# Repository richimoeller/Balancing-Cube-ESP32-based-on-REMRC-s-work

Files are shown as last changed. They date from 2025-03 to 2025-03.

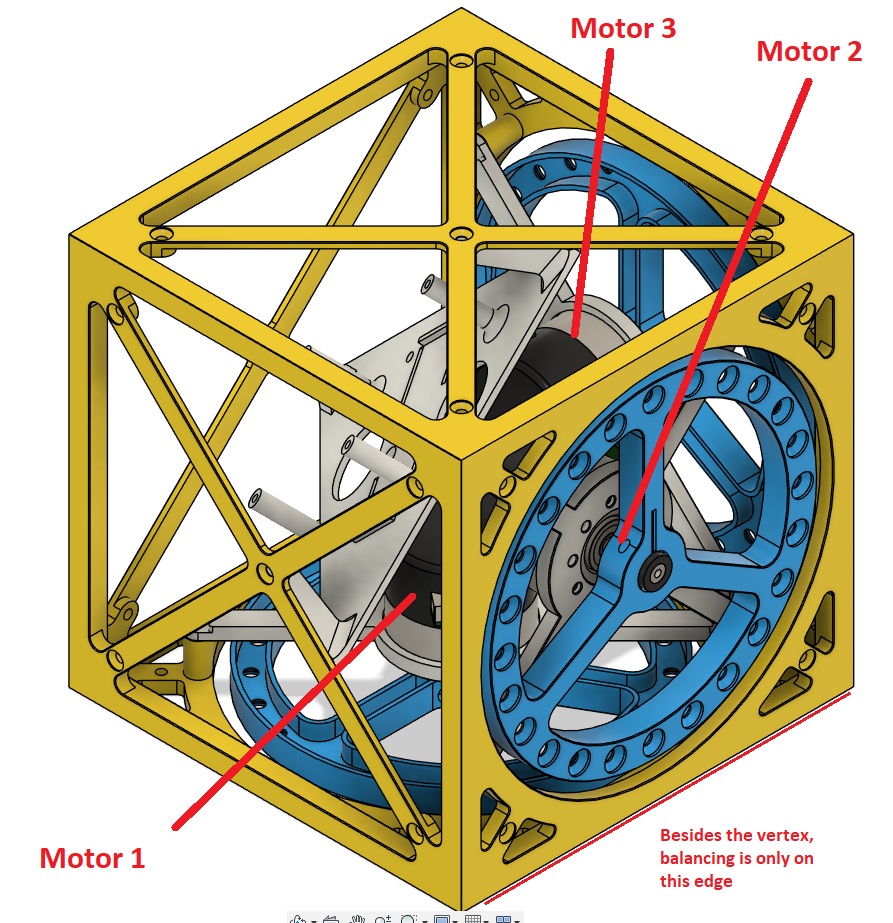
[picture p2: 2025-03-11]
pictures/orientation_motors.jpg

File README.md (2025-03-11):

Balancing Cube ESP32 based on REMRC's work
------------------------------------------

There already a few cubes out there based on REMRCs design.

All the credits go to him.

I redesigned the cube in Fusion 360 since I wanted to have an unobstructed view at the reaction wheels. All other parts are following closely REMRC's design.
Basically the cube worked right from the start with no changing of the tuning parameters needed. My reaction wheels have a weight of 72g. I use a 11,1V 550mAh battery.
The code uses the encoders. You have to wire them to the ESP32(30pin). I needed to change the code a little because the pwm_channel assignment used by REMRC is deprecated meanwhile.

Just follow the calibration procedure provided by REMRC.

I also added the functionality of letting the cube turn on its vertex by sending the commands r+, r- and rs(Stop) via a bluetooth terminal. However the cube will not turn forever in one direction. The wheels will speed up and eventually saturate. Just change the direction or stop it in due time. 

https://www.youtube.com/watch?v=GABWHTa6_v8

I added motor numbers to the schematic as well as to the 3D picture. This way you should be able to connect the motors in the correct order right from the beginning. Feel free to use the Fritzing-board provided. 

It's an amazing project. Enjoy!!

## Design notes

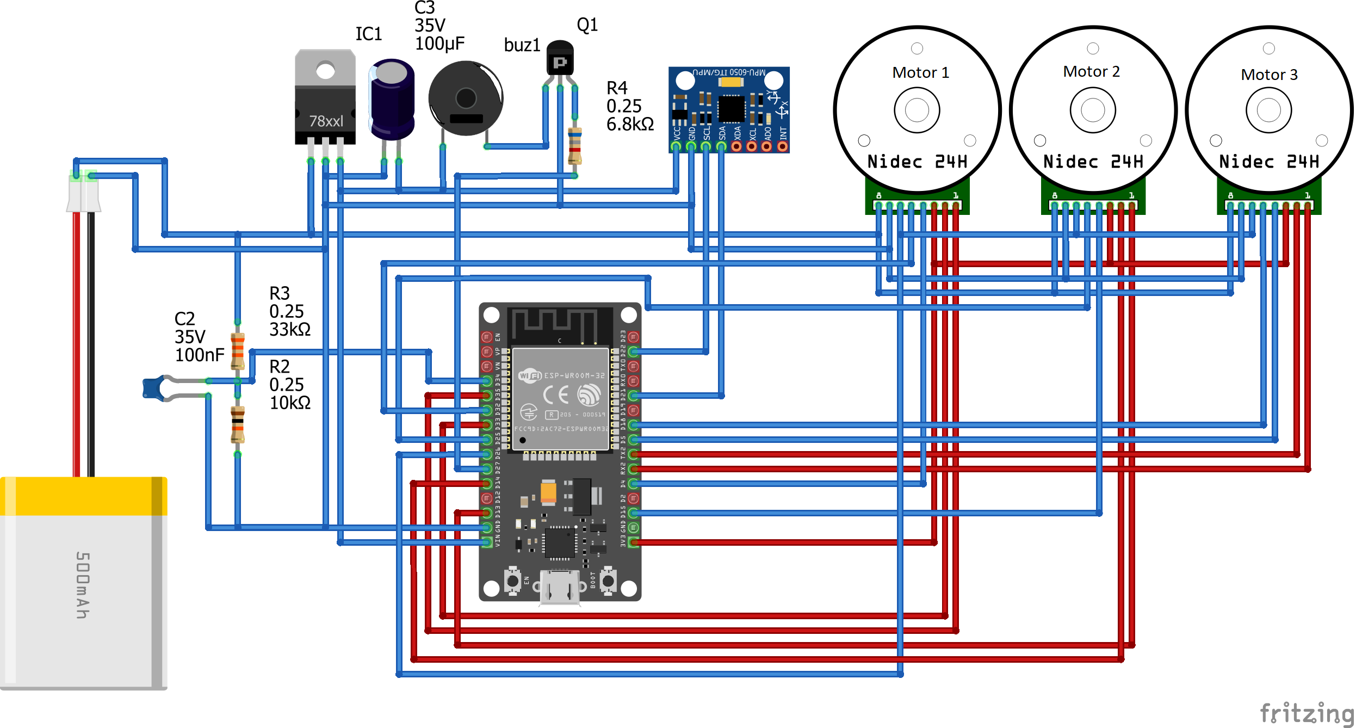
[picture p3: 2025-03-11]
pictures/schematic.png

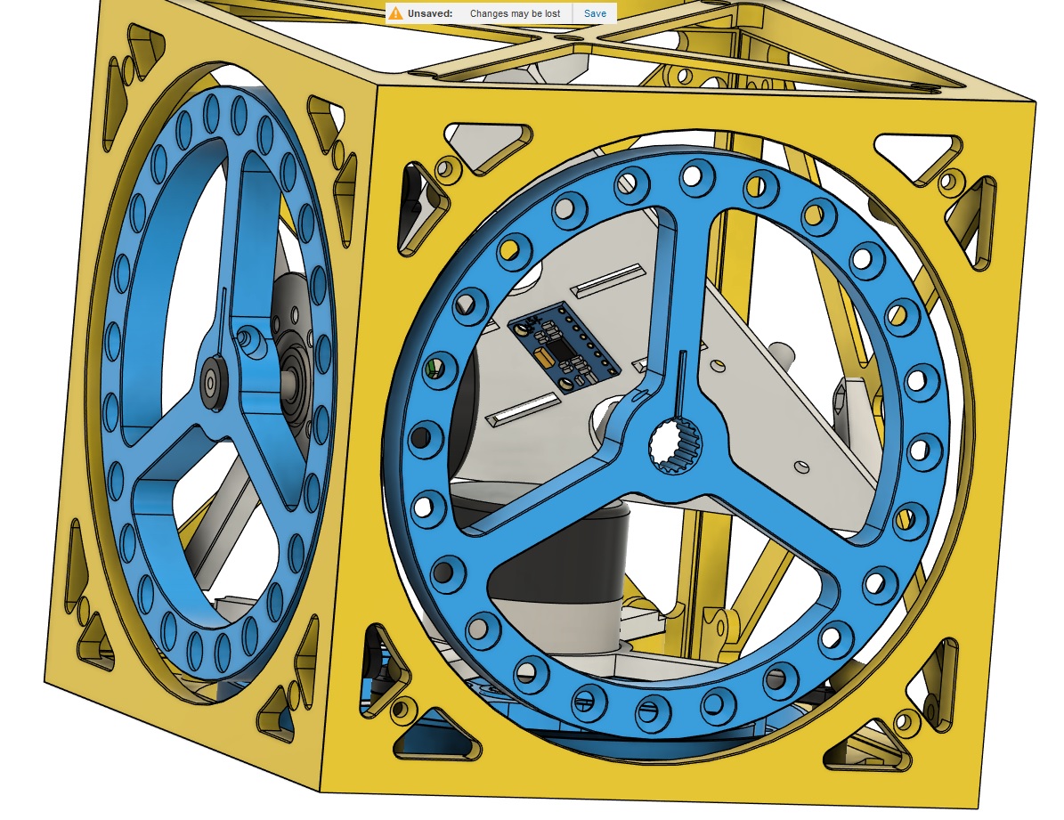
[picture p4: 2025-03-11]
pictures/orientation_mpu6050.jpg

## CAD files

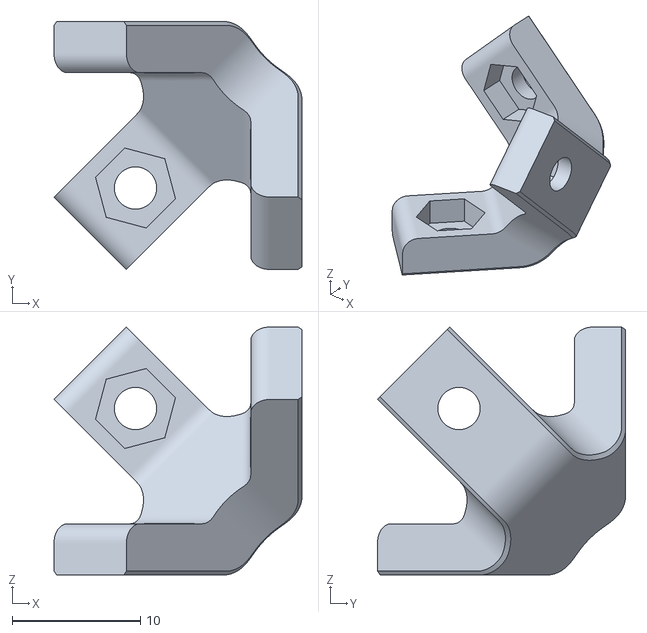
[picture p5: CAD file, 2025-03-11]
stl_files/Corner_8x.stl
19.4 x 19.4 x 19.4

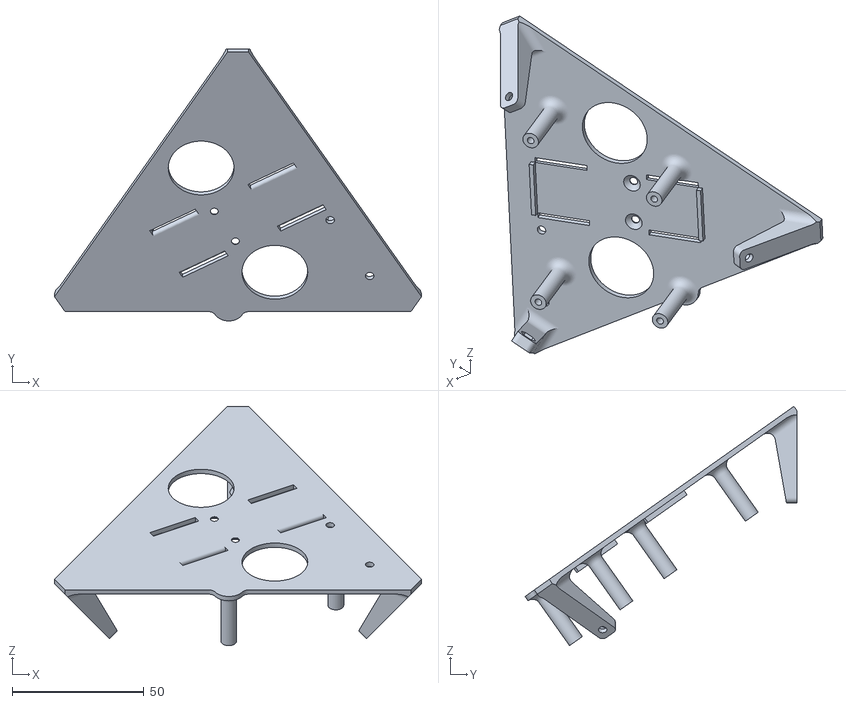
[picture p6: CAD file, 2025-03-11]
stl_files/Electronics_holder_1x.stl
139.4 x 103.3 x 90.9

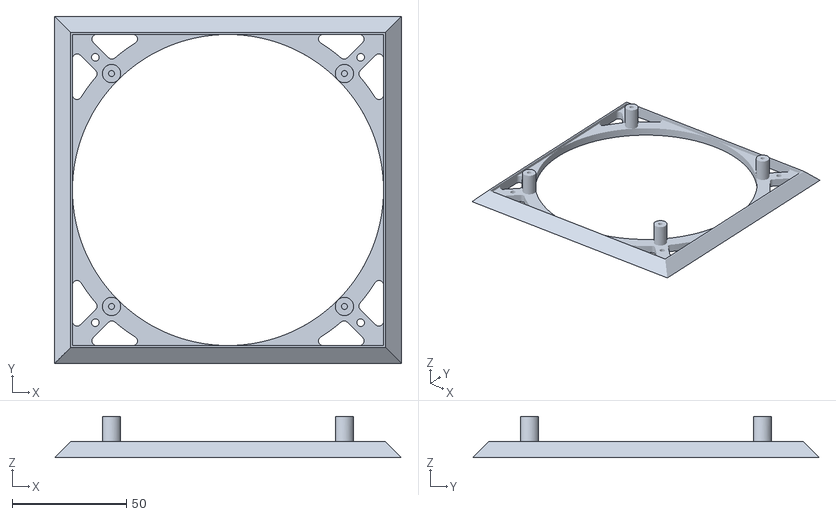
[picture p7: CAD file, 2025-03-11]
stl_files/Cube_Side_reaction_wheel_3x.stl
151.7 x 151.7 x 18.0

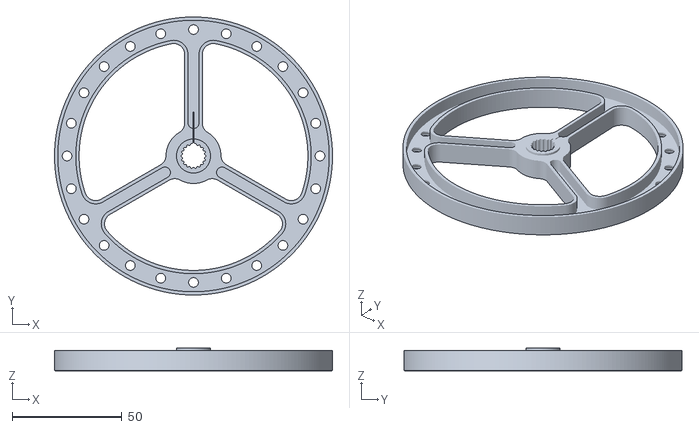
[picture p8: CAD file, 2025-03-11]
stl_files/Reaction_wheel_3x.stl
126.4 x 126.4 x 10.4

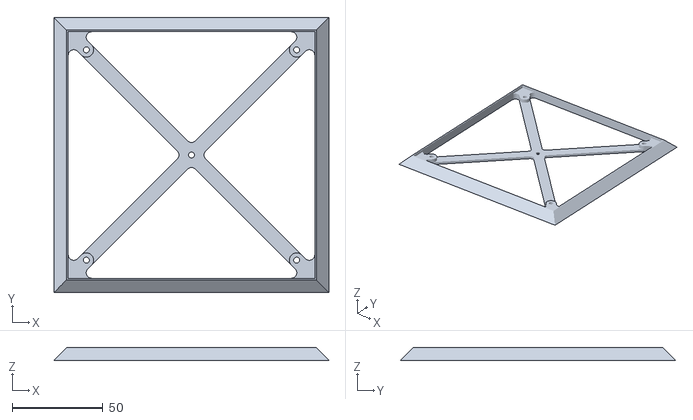
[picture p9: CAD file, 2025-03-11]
stl_files/Cube_Side_no_wheel_3x.stl
151.7 x 151.7 x 7.00

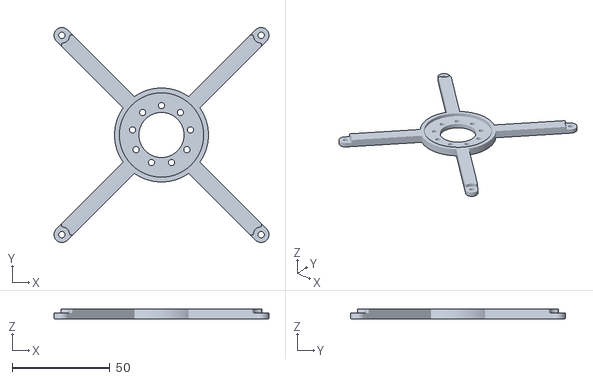
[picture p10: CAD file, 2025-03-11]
stl_files/Motor_holder_3x.stl
109.8 x 109.8 x 5.00

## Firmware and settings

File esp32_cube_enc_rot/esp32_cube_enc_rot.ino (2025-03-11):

#include "ESP32.h"
#include <Wire.h>
#include <EEPROM.h>
#include "BluetoothSerial.h"
#include <FastLED.h>

BluetoothSerial SerialBT;
CRGB leds[NUM_PIXELS];

void setup() {
  Serial.begin(115200);
  SerialBT.begin("ESP32-Test"); // Bluetooth device name
  EEPROM.begin(EEPROM_SIZE);
  
  FastLED.addLeds<WS2812B, LED_PIN, RGB>(leds, NUM_PIXELS);  // GRB ordering is typical
  
  pinMode(BUZZER, OUTPUT);
  pinMode(BRAKE, OUTPUT);
  digitalWrite(BRAKE, LOW);

  for (int i=0;i<=255;i+=10) {
    leds[0] = CRGB(i, 0, 0);
    leds[1] = CRGB(i, 0, 0);
    leds[2] = CRGB(i, 0, 0);
    FastLED.show();
    delay(5);
  }
  delay(300);
  for (int i=0;i<=255;i+=10) {
    leds[0] = CRGB(0, i, 0);
    leds[1] = CRGB(0, i, 0);
    leds[2] = CRGB(0, i, 0);
    FastLED.show();
    delay(5);
  }
  delay(300);
  for (int i=0;i<=255;i+=10) {
    leds[0] = CRGB(0, 0, i);
    leds[1] = CRGB(0, 0, i);
    leds[2] = CRGB(0, 0, i);
    FastLED.show();
    delay(5);
  }
  delay(300);
  leds[0] = CRGB::Black;
  leds[1] = CRGB::Black;
  leds[2] = CRGB::Black;
  FastLED.show();
  
  pinMode(DIR1, OUTPUT);
  pinMode(ENC1_1, INPUT);
  pinMode(ENC1_2, INPUT);
  attachInterrupt(ENC1_1, ENC1_READ, CHANGE);
  attachInterrupt(ENC1_2, ENC1_READ, CHANGE);
  // ledcSetup(PWM1_CH, BASE_FREQ, TIMER_BIT);
  ledcAttach(PWM1, BASE_FREQ, TIMER_BIT);
  Motor1_control(0);
  
  pinMode(DIR2, OUTPUT);
  pinMode(ENC2_1, INPUT);
  pinMode(ENC2_2, INPUT);
  attachInterrupt(ENC2_1, ENC2_READ, CHANGE);
  attachInterrupt(ENC2_2, ENC2_READ, CHANGE);
  //ledcSetup(PWM2_CH, BASE_FREQ, TIMER_BIT);
  ledcAttach(PWM2, BASE_FREQ, TIMER_BIT);
  Motor2_control(0);
  
  pinMode(DIR3, OUTPUT);
  pinMode(ENC3_1, INPUT);
  pinMode(ENC3_2, INPUT);
  attachInterrupt(ENC3_1, ENC3_READ, CHANGE);
  attachInterrupt(ENC3_2, ENC3_READ, CHANGE);
  //ledcSetup(PWM3_CH, BASE_FREQ, TIMER_BIT);
  ledcAttach(PWM3, BASE_FREQ, TIMER_BIT);
  Motor3_control(0);

  EEPROM.get(0, offsets);
  if (offsets.ID == 96) 
    calibrated = true;

  delay(200);
  angle_setup();

}

void loop() {
  currentT = millis();
  if (currentT - previousT_1 >= loop_time) {
    Tuning();
    angle_calc();

    motor1_speed = enc_count1;
    enc_count1 = 0;
    motor2_speed = enc_count2;
    enc_count2 = 0;
    motor3_speed = enc_count3;
    enc_count3 = 0;
    threeWay_to_XY(motor1_speed, motor2_speed, motor3_speed);
    motors_speed_Z = motor1_speed + motor2_speed + motor3_speed;
    
    if (vertical_vertex && calibrated && !calibrating) {    
      digitalWrite(BRAKE, HIGH);
      gyroX = GyX / 131.0;
      gyroY = GyY / 131.0;
      gyroZ = GyZ / 131.0;
      gyroXfilt = alpha * gyroX + (1 - alpha) * gyroXfilt;
      gyroYfilt = alpha * gyroY + (1 - alpha) * gyroYfilt;
      
      int pwm_X = constrain(K1 * robot_angleX + K2 * gyroXfilt + K3 * speed_X + K4 * motors_speed_X, -255, 255);
      int pwm_Y = constrain(K1 * robot_angleY + K2 * gyroYfilt + K3 * speed_Y + K4 * motors_speed_Y, -255, 255);
      int pwm_Z = constrain(zK2 * gyroZ + zK3 * motors_speed_Z, -255, 255);

      motors_speed_X += speed_X / 5; 
      motors_speed_Y += speed_Y / 5;
      XYZ_to_threeWay(-pwm_X, pwm_Y, -pwm_Z);
    } else if (vertical_edge && calibrated && !calibrating) {
      digitalWrite(BRAKE, HIGH);
      gyroX = GyX / 131.0;
      gyroXfilt = alpha * gyroX + (1 - alpha) * gyroXfilt;
      
      int pwm_X = constrain(eK1 * robot_angleX + eK2 * gyroXfilt + eK3 * motor3_speed + eK4 * motors_speed_X, -255, 255);
      
      motors_speed_X += motor3_speed / 5;
      Motor3_control(pwm_X);
    } else {
      XYZ_to_threeWay(0, 0, 0);
      digitalWrite(BRAKE, LOW);
      motors_speed_X = 0;
      motors_speed_Y = 0;
    }
    previousT_1 = currentT;
  }
  else {
      Rotating();
  }
  
  if (currentT - previousT_2 >= 2000) {    
    battVoltage((double)analogRead(VBAT) / 204); // value 204 must be selected by measuring battery voltage!
    if (!calibrated && !calibrating) {
      SerialBT.println("first you need to calibrate the balancing points...");
      Serial.println("first you need to calibrate the balancing points (over bluetooth)...");
      if (!calibrated_leds) {
        leds[0] = CRGB(0, 255, 0);
        leds[1] = CRGB(0, 255, 0);
        leds[2] = CRGB(0, 255, 0);
        FastLED.show();
        calibrated_leds = true; 
      } else {
        leds[0] = CRGB::Black;
        leds[1] = CRGB::Black;
        leds[2] = CRGB::Black;
        FastLED.show();
        calibrated_leds = false; 
      }
    }
    previousT_2 = currentT;
  }  
}

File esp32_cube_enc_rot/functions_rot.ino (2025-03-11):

void writeTo(byte device, byte address, byte value) {
  Wire.beginTransmission(device);
  Wire.write(address);
  Wire.write(value);
  Wire.endTransmission(true);
}

void beep() {
    digitalWrite(BUZZER, HIGH);
    delay(70);
    digitalWrite(BUZZER, LOW);
    delay(80);
}

void save() {
    EEPROM.put(0, offsets);
    EEPROM.commit();
    EEPROM.get(0, offsets);
    if (offsets.ID == 96) calibrated = true;
    calibrating = false;
    SerialBT.println("Calibrating off.");
    beep();
}

void angle_setup() {
  Wire.begin();
  delay (100);
  writeTo(MPU6050, PWR_MGMT_1, 0);
  writeTo(MPU6050, ACCEL_CONFIG, accSens << 3); // Specifying output scaling of accelerometer
  writeTo(MPU6050, GYRO_CONFIG, gyroSens << 3); // Specifying output scaling of gyroscope
  delay (100);
  
  beep();
  leds[2] = CRGB(0, 0, 200);
  FastLED.show();
  for (int i = 0; i < 512; i++) {
    angle_calc();
    GyZ_offset_sum += GyZ;
    delay(5);
  }
  GyZ_offset = GyZ_offset_sum >> 9;
  Serial.print("GyZ offset value = "); Serial.println(GyZ_offset);
  beep();
  leds[2] = CRGB::Black;
  FastLED.show();

  leds[1] = CRGB(0, 0, 200);
  FastLED.show();
  for (int i = 0; i < 512; i++) {
    angle_calc();
    GyY_offset_sum += GyY;
    delay(5);
  }
  GyY_offset = GyY_offset_sum >> 9;
  Serial.print("GyY offset value = "); Serial.println(GyY_offset);
  beep();
  leds[1] = CRGB::Black;
  FastLED.show();

  leds[0] = CRGB(0, 0, 200);
  FastLED.show();
  for (int i = 0; i < 512; i++) {
    angle_calc();
    GyX_offset_sum += GyX;
    delay(5);
  }
  GyX_offset = GyX_offset_sum >> 9;
  Serial.print("GyX offset value = "); Serial.println(GyX_offset);
  beep();
  beep();
  leds[0] = CRGB::Black;
  FastLED.show();

  leds[0] = CRGB(255, 0, 0);
  leds[1] = CRGB(255, 0, 0);
  leds[2] = CRGB(255, 0, 0);
  FastLED.show();
  delay(300);
  leds[0] = CRGB::Black;
  leds[1] = CRGB::Black;
  leds[2] = CRGB::Black;
  FastLED.show();
  delay(150);
  leds[0] = CRGB(255, 0, 0);
  leds[1] = CRGB(255, 0, 0);
  leds[2] = CRGB(255, 0, 0);
  FastLED.show();
  delay(300);
  leds[0] = CRGB::Black;
  leds[1] = CRGB::Black;
  leds[2] = CRGB::Black;
  FastLED.show();
  delay(300);
}

void angle_calc() {
  
  Wire.beginTransmission(MPU6050);
  Wire.write(0x43);
  Wire.endTransmission(false);
  Wire.requestFrom(MPU6050, 6, true);  
  GyX = Wire.read() << 8 | Wire.read();
  GyY = Wire.read() << 8 | Wire.read();
  GyZ = Wire.read() << 8 | Wire.read();

  Wire.beginTransmission(MPU6050);
  Wire.write(0x3B);                  
  Wire.endTransmission(false);
  Wire.requestFrom(MPU6050, 6, true); 
  AcX = Wire.read() << 8 | Wire.read();
  AcY = Wire.read() << 8 | Wire.read();
  AcZ = Wire.read() << 8 | Wire.read();

  if (abs(AcX) < 2000) {
    AcXc = AcX - offsets.acXv;
    AcYc = AcY - offsets.acYv;
    AcZc = AcZ - offsets.acZv;
  } else {
    AcXc = AcX - offsets.acXe;
    AcYc = AcY - offsets.acYe;
    AcZc = AcZ - offsets.acZe;
  }
  GyZ -= GyZ_offset;
  GyY -= GyY_offset;
  GyX -= GyX_offset;

  robot_angleY += GyY * loop_time / 1000 / 65.536;
  Acc_angleY = atan2(AcXc, -AcZc) * 57.2958;
  robot_angleY = robot_angleY * Gyro_amount + Acc_angleY * (1.0 - Gyro_amount);

  robot_angleX += GyX * loop_time / 1000 / 65.536;
  Acc_angleX = -atan2(AcYc, -AcZc) * 57.2958;
  robot_angleX = robot_angleX * Gyro_amount + Acc_angleX * (1.0 - Gyro_amount);

  if (abs(AcX) < 2000 && abs(Acc_angleX) < 0.4 && abs(Acc_angleY) < 0.4 && !vertical_vertex && !vertical_edge) {
    robot_angleX = Acc_angleX;
    robot_angleY = Acc_angleY;
    vertical_vertex = true;
  } else if (abs(AcX) > 7000 && abs(AcX) < 10000 && abs(Acc_angleX) < 0.3 && !vertical_vertex && !vertical_edge) {
    robot_angleX = Acc_angleX;
    robot_angleY = Acc_angleY;
    vertical_edge = true;
  } else if ((abs(robot_angleX) > 7 || abs(robot_angleY) > 7) && vertical_vertex) {
    vertical_vertex = false;
  } else if ((abs(robot_angleX) > 7 || abs(robot_angleY) > 7) && vertical_edge) {
    vertical_edge = false;
  }
}

void XYZ_to_threeWay(float pwm_X, float pwm_Y, float pwm_Z) {
  int16_t m1 = round((0.5 * pwm_X - 0.866 * pwm_Y) / 1.37 + pwm_Z);  
  int16_t m2 = round((0.5 * pwm_X + 0.866 * pwm_Y) / 1.37 + pwm_Z);
  int16_t m3 = -pwm_X / 1.37 + pwm_Z;  
  if (!rotating) pwm_offset = 0;
  Motor1_control(m1 + pwm_offset);
  Motor2_control(m2 + pwm_offset);
  Motor3_control(m3 + pwm_offset);
}

void threeWay_to_XY(int in_speed1, int in_speed2, int in_speed3) {
  speed_X = ((in_speed3 - (in_speed2 + in_speed1) * 0.5) * 0.5) * 1.81;
  speed_Y = -(-0.866 * (in_speed2 - in_speed1)) / 1.1;
}

void battVoltage(double voltage) {
  if (voltage > 8 && voltage <= 9.5) {
    digitalWrite(BUZZER, HIGH);
  } else {
    digitalWrite(BUZZER, LOW);
  }
}

void pwmSet(uint8_t channel, uint32_t value) {
  ledcWrite(channel, value);
}

void Motor1_control(int sp) {
  sp = sp + motor1_speed;
  if (sp < 0) 
    digitalWrite(DIR1, LOW);
  else 
    digitalWrite(DIR1, HIGH);
  pwmSet(PWM1, 255 - abs(sp));  //changed from PWMx_CH to PWMx
}

void Motor2_control(int sp) {
  sp = sp + motor2_speed;
  if (sp < 0) 
    digitalWrite(DIR2, LOW);
  else 
    digitalWrite(DIR2, HIGH);
  pwmSet(PWM2, 255 - abs(sp));  //changed from PWMx_CH to PWMx
}

void Motor3_control(int sp) {
  sp = sp + motor3_speed;
  if (sp < 0) 
    digitalWrite(DIR3, LOW);
  else 
    digitalWrite(DIR3, HIGH);
  pwmSet(PWM3, 255 - abs(sp));  //changed from PWMx_CH to PWMx
}

void ENC1_READ() {
  static int state = 0;
  state = (state << 2 | (digitalRead(ENC1_1) << 1) | digitalRead(ENC1_2)) & 0x0f;
  if (state == 0x02 || state == 0x0d || state == 0x04 || state == 0x0b) {
    enc_count1++;
  } else if (state == 0x01 || state == 0x0e || state == 0x08 || state == 0x07) {
    enc_count1--;
  }
}

void ENC2_READ() {
  static int state = 0;
  state = (state << 2 | (digitalRead(ENC2_1) << 1) | digitalRead(ENC2_2)) & 0x0f;
  if (state == 0x02 || state == 0x0d || state == 0x04 || state == 0x0b) {
    enc_count2++;
  } else if (state == 0x01 || state == 0x0e || state == 0x08 || state == 0x07) {
    enc_count2--;
  }
}

void ENC3_READ() {
  static int state = 0;
  state = (state << 2 | (digitalRead(ENC3_1) << 1) | digitalRead(ENC3_2)) & 0x0f;
  if (state == 0x02 || state == 0x0d || state == 0x04 || state == 0x0b) {
    enc_count3++;
  } else if (state == 0x01 || state == 0x0e || state == 0x08 || state == 0x07) {
    enc_count3--;
  }
}
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
